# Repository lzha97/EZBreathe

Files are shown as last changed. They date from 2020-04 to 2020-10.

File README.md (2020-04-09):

# DIY-Ventilator-Design-Challenge
Project Proposal for Columbia University DIY-Ventilator-Design-Challenge (April 2-6)

https://engineering.columbia.edu/diy-ventilator-challenge

**Project Team Members:** Annie Lin, Mojde Yadollahikhales, Isabela Yepes, Lillian Zha 

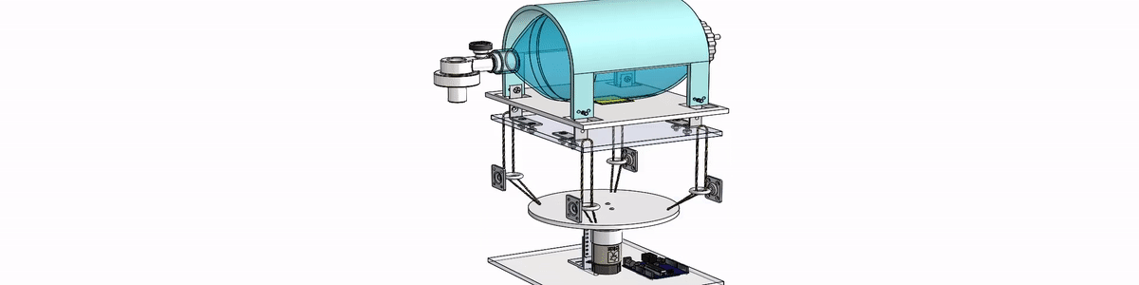
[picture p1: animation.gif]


## Included: 

- Animation of Pump Mechanism 
- CAD files for design parts (credit to Annie Lin)
- Total Assembly CAD file
- Proposal Presentation
- mp4 of Animation

## To be added: 

- Arduino Code (if our project gets selected for funding)

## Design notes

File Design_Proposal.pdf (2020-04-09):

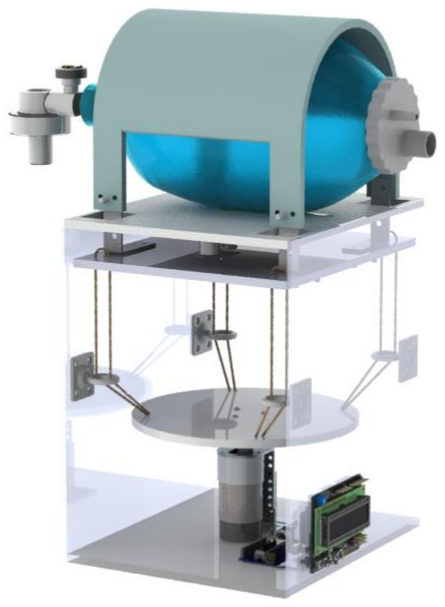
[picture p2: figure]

# EZBreathe

### Automated Ambu-Bag Pump

Annie Lin
SEAS 20’
zl2542@columbia.edu
(469)-583-7481

Isabela Yepes
SEAS 22’
imy2103@columbia.edu
(914) 308-0641

Mojde Yadollahikhales
SEAS 20’
my2511@columbia.edu
(832) 664-0195

Lillian Zha
SEAS 20’
lz2527@columbia.edu
(972)-352-9532

## COVID-19 DIY Ventilator Design Challenge Proposal

GitHub Link (https://github.com/lzha97/DIY-Ventilator-Design-Challenge)

# Overview

### - Pumping Animation - Motivation Highlights - Our Team!

# Link to Animation Video

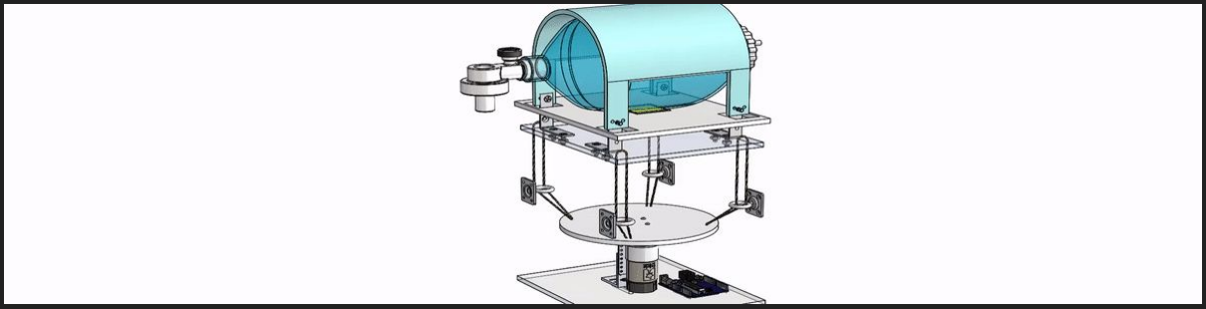
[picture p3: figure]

https://youtu.be/aiGK7Tza4vM

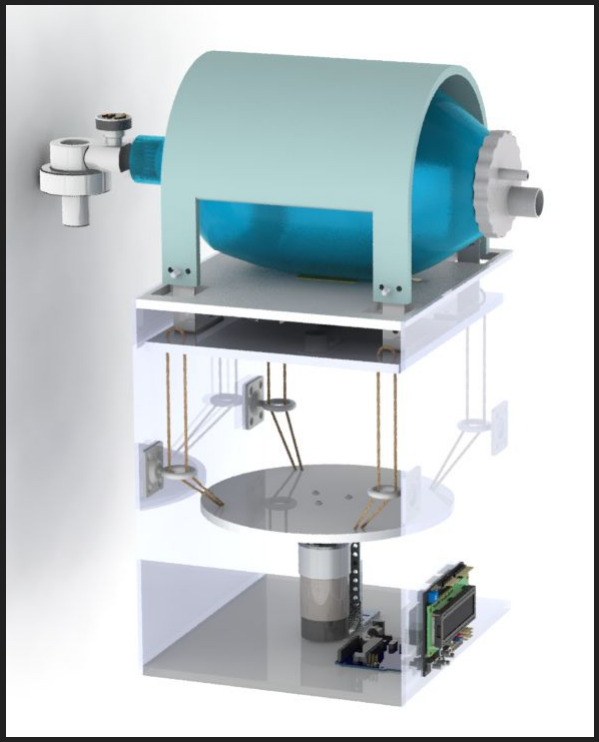
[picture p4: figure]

# Motivation Highlights

- Easy ambu-bag replacement - Cover grips to fit any ambu-bag volume size as it squeezes - Force applied from only one motor (few mechanical parts) - No 3D printing required - True DIY - quick and easy assembly with readily available pieces - Low resource countries with no makerspace facilities can replicate - Operates for at least 15 days - Attempt at patient-paced inhalation

# Our Team!

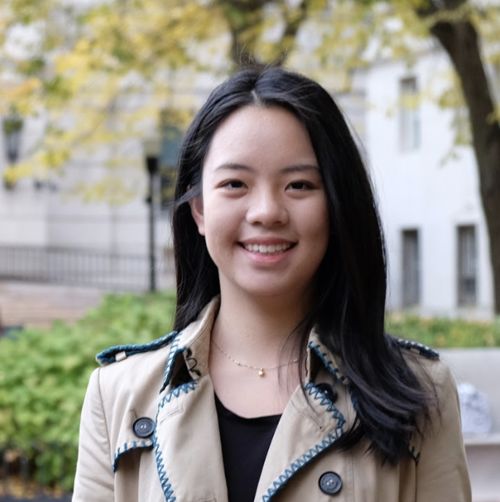
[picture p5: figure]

Annie Lin
Mechanical Engineering

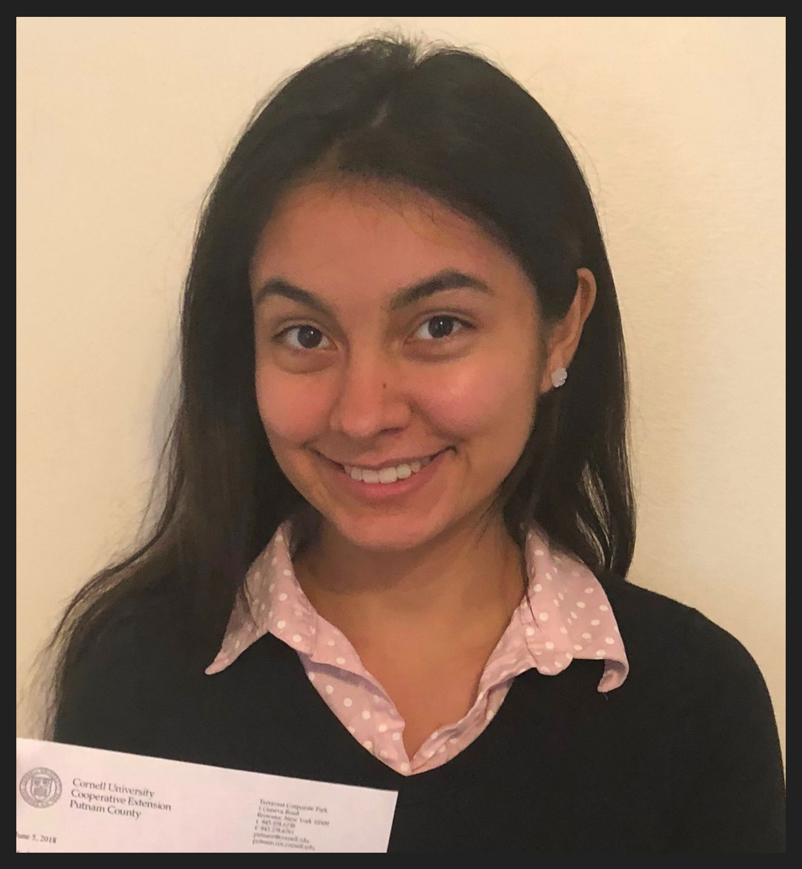
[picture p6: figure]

Isabela Yepes
Earth & Environmental
Engineering

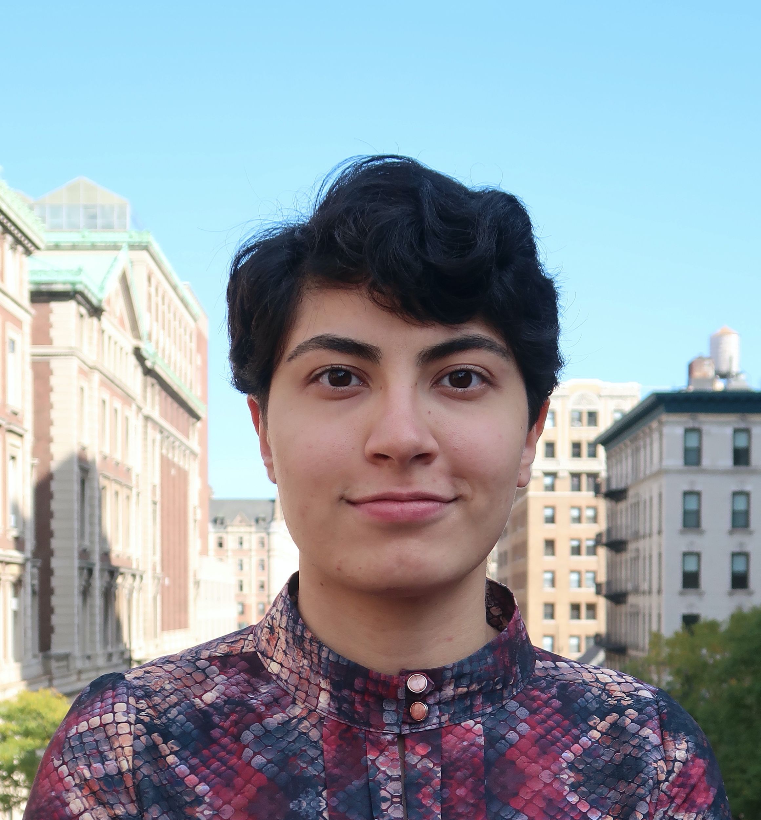
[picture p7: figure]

Mojde Yadollahikhales
BioMedical Engineering

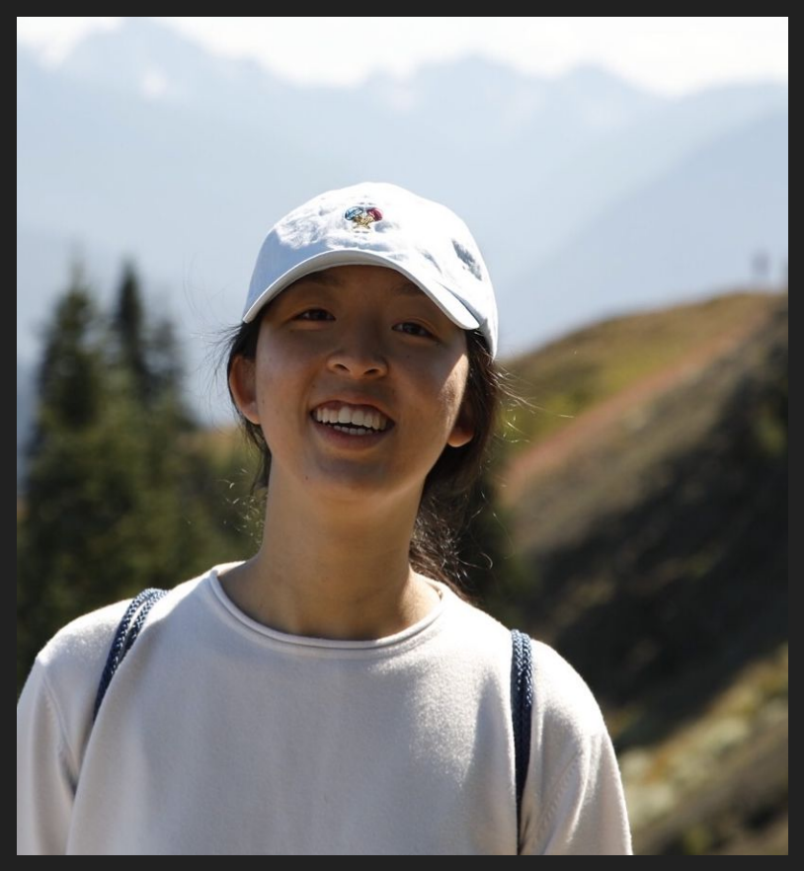
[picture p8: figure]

Lillian Zha
Computer Science

# Design Schema

### - Design Overview - CAD Renderings - String Attachment - Exploded Parts View - Design Versions for Ultrasonic Sensor Placement - Electronic Schematics

# Design Overview

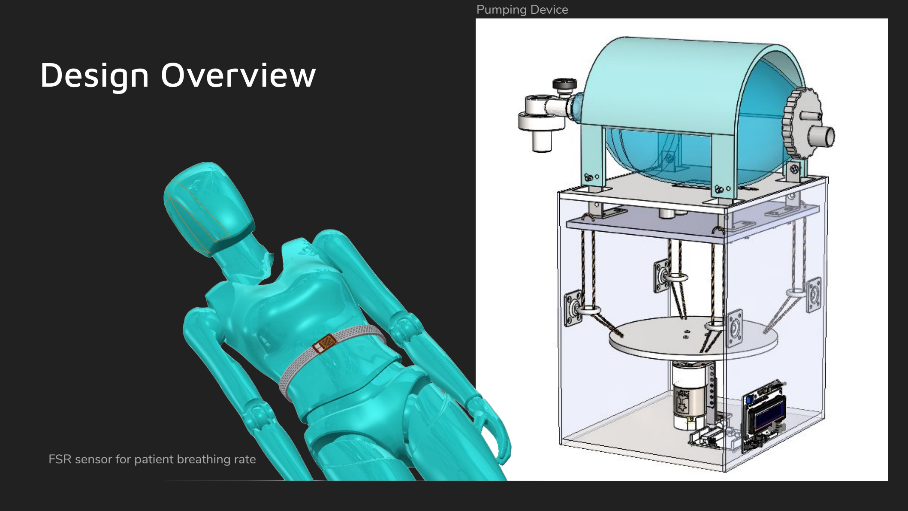
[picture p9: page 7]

FSR sensor for patient breathing rate

Pumping Device

# CAD Rendering

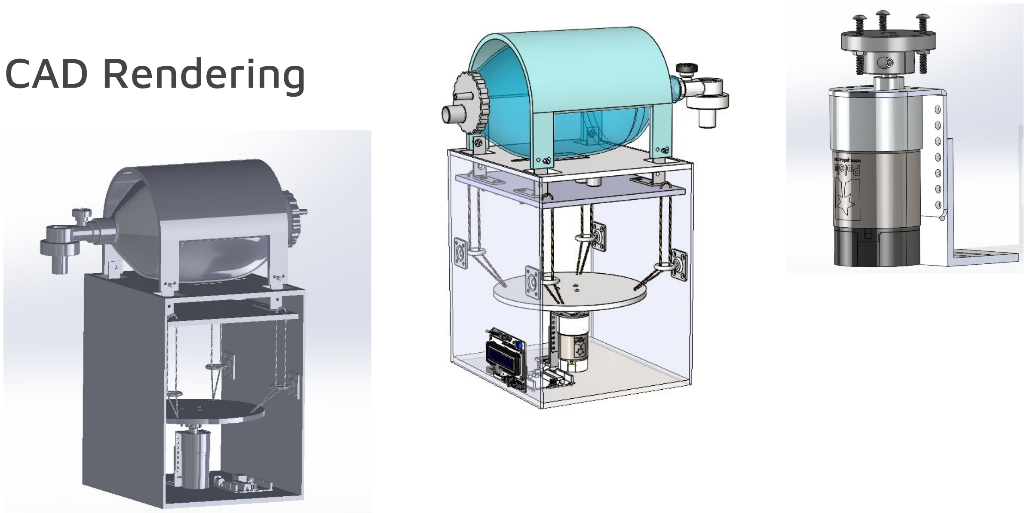
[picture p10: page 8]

# CAD Rendering (Continued)

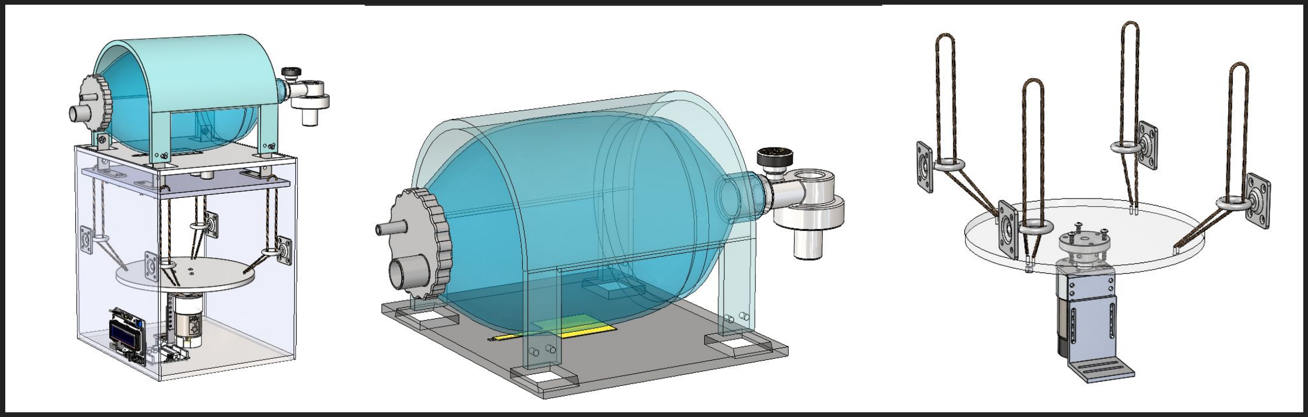
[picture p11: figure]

# String Attachment

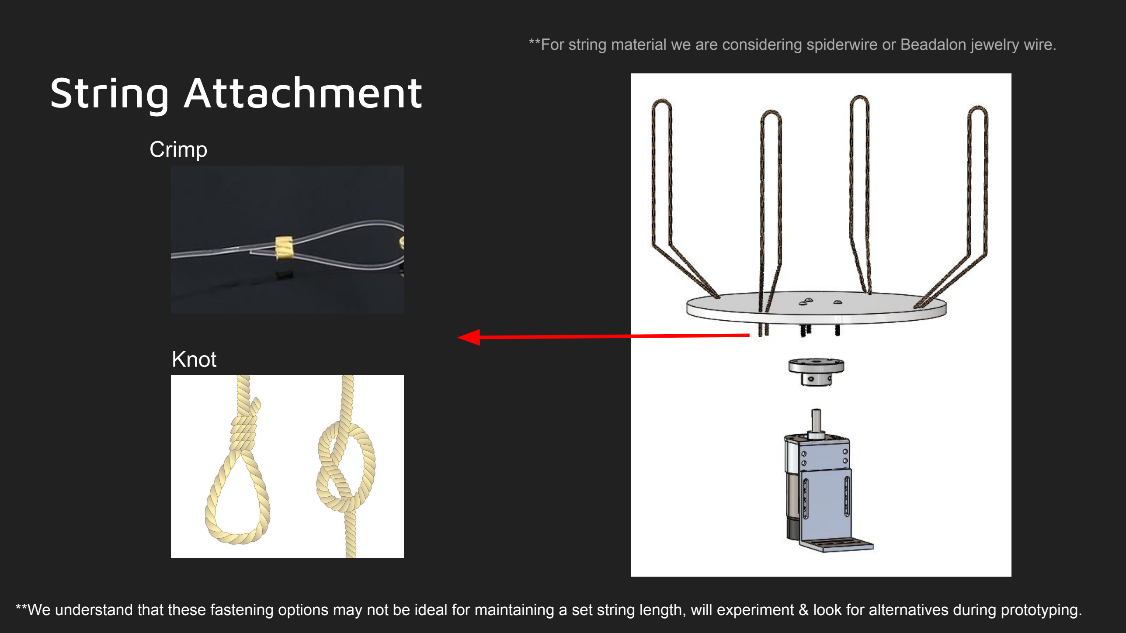
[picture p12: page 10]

**We understand that these fastening options may not be ideal for maintaining a set string length, will experiment & look for alternatives during prototyping.

Knot

Crimp

**For string material we are considering spiderwire or Beadalon jewelry wire.

# Exploded Parts View

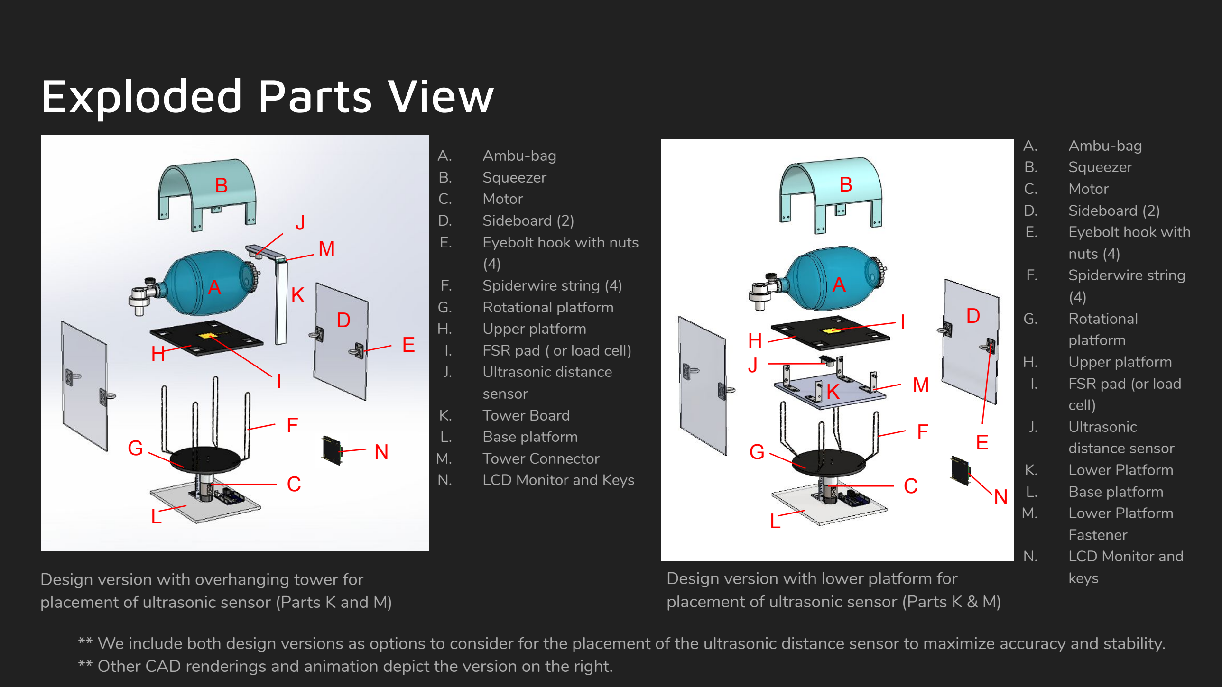
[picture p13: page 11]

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
A. Ambu-bag
B. Squeezer
C. Motor
D. Sideboard (2)
E. Eyebolt hook with
nuts (4)
F. Spiderwire string
(4)
G. Rotational
platform
H. Upper platform
I. FSR pad (or load
cell)
J. Ultrasonic
distance sensor
K. Lower Platform
L. Base platform
M. Lower Platform
Fastener
N. LCD Monitor and
keys

A

B

Design version with overhanging tower for placement of ultrasonic sensor (Parts K and M)

Design version with lower platform for placement of ultrasonic sensor (Parts K & M)

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
** We include both design versions as options to consider for the placement of the ultrasonic distance sensor to maximize accuracy and stability. ** Other CAD renderings and animation depict the version on the right.

A. Ambu-bag
B. Squeezer
C. Motor
D. Sideboard (2)
E. Eyebolt hook with nuts
(4)
F. Spiderwire string (4)
G. Rotational platform
H. Upper platform
I. FSR pad ( or load cell)
J. Ultrasonic distance
sensor
K. Tower Board
L. Base platform
M. Tower Connector
N. LCD Monitor and Keys

N

N

# K,M Design Parts for Ultrasonic Sensor Placement

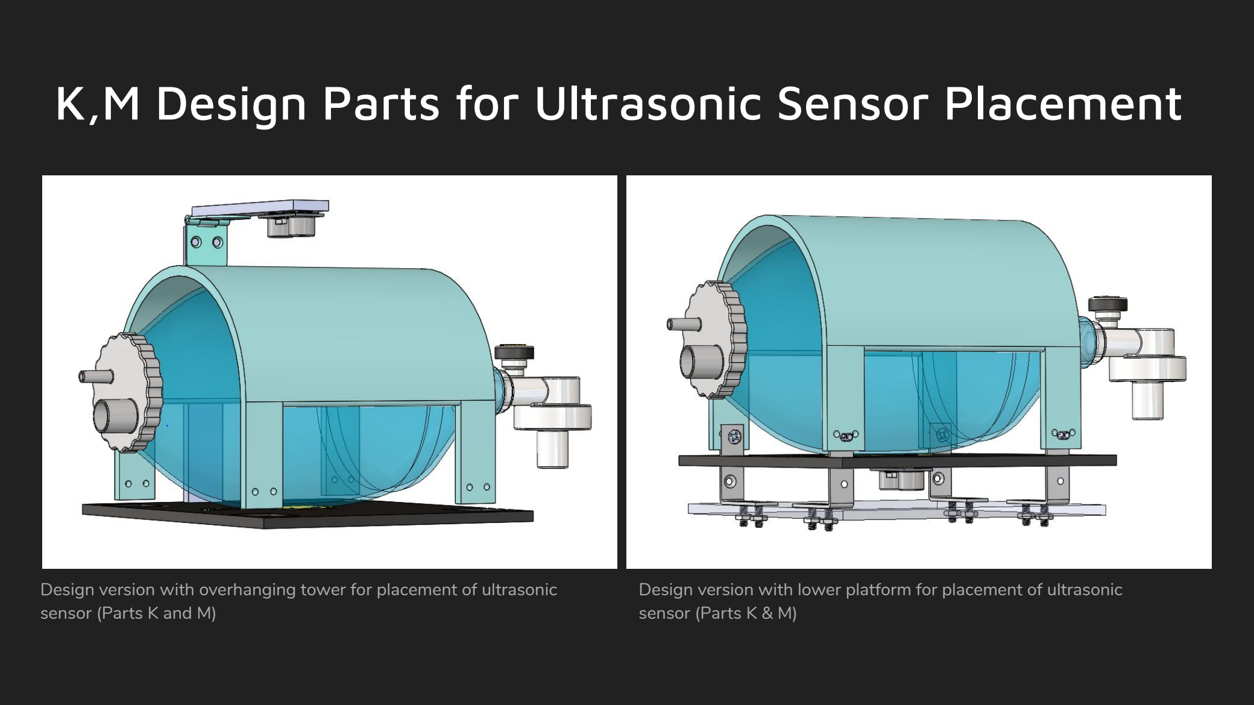
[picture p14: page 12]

Design version with overhanging tower for placement of ultrasonic sensor (Parts K and M)

Design version with lower platform for placement of ultrasonic sensor (Parts K & M)

# Electronic Schematic

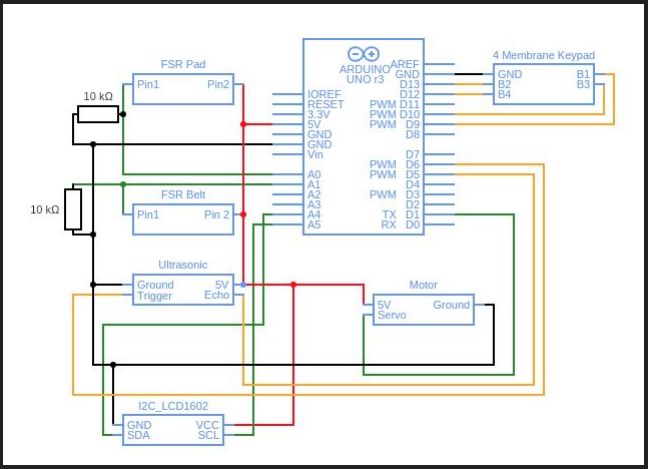
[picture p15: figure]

# Functionality Overview &

# Limitations

### - Pumping Mechanism Overview - Sensing Mechanisms Overview - Design Specifications - Sensors & Sensed Conditions - Sensing/Alarm Algorithm - Design Limitations

# Functionality Overview

### Pumping Mechanism:

This automated bag pumping design uses the concept behind linear twisted string actuators to minimize the number of mechanical parts (gears/pulleys/motors/servos etc.) needed to build the DIY pump.

The main components consist of a single motor, string and plastic squeezer above the bag.

When the motor rotates, the strings are twisted so that their overall vertical length is decreased. This decrease in vertical string length will exert a pulling force on the
squeezer placed above the bag, causing it to press down
on the bag. Increasing amplitude (pressure on ambu-bag)

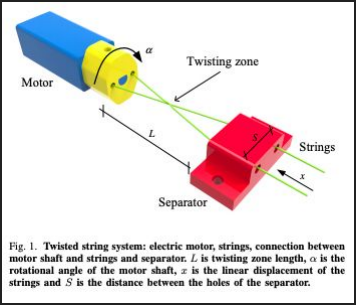
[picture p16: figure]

requires increased motor rotation. | Figure above shows theory basis for the twisting
| linear actuator mechanism from Tavakoli 2016.

# Functionality Overview (Continued)

### Sensing Mechanisms:

A shortcoming of many DIY ventilator designs are that they force patients to breathe at a set frequency. Our design uses a sensing mechanism to try to address this problem and allow patients to breathe at their own pace as long as it is above a threshold rate.

A force resistive sensor (FSR) will be placed on the patient’s stomach above the diaphragm. Ambu-bag will be pumped after detecting patient’s attempt to breathe. To prevent over-pumping of the lungs, a protective mechanism will be put in place allowing the user to set an Upper Rate Interval (URI), above which the bag will not be pumped.

The system also intakes an intrinsic Lower Rate Interval (LRI) from the user (doctor) to maintain a minimum required pump rate in the case of patient sedation/unconsciousness or lack of ability to noticeably move the stomach area.

Desired compression amplitude provided by the user will be monitored by an ultrasonic distance sensor to remove the need for constant check-ins by nurses or personnel. Similarly, the pumping rate is monitored by another FSR (or load cell) under the Ambu-bag placed under the Ambu-bag. Both of these sensors and alarm thresholds will be relative and calibrated upon powering of the system.

Finally, the FSR under the Ambu-bag and the ultrasonic distance sensor will also be used to measure the compression force and compression distance in order to ensure no leakage or other issues associated with the ambu bag and pump. All of these sensor mechanisms will work towards patient comfort and alleviating need for nurse monitoring.

# Specifications

Minimum rate: 10 bpm (pumps per min) Maximum rate: 30 bpm Maximum force: 100N (based on motor) Amplitude range: 2-15 cm Sensed Conditions: pressure drop, patient-paced inhalation, pump rate, amplitude control Safety Measures: - Alarms when the pressure drops below threshold or desired amplitude is not reached => system is failing - Has an intrinsic pump rate that will be enforced if patient breathing goes undetected

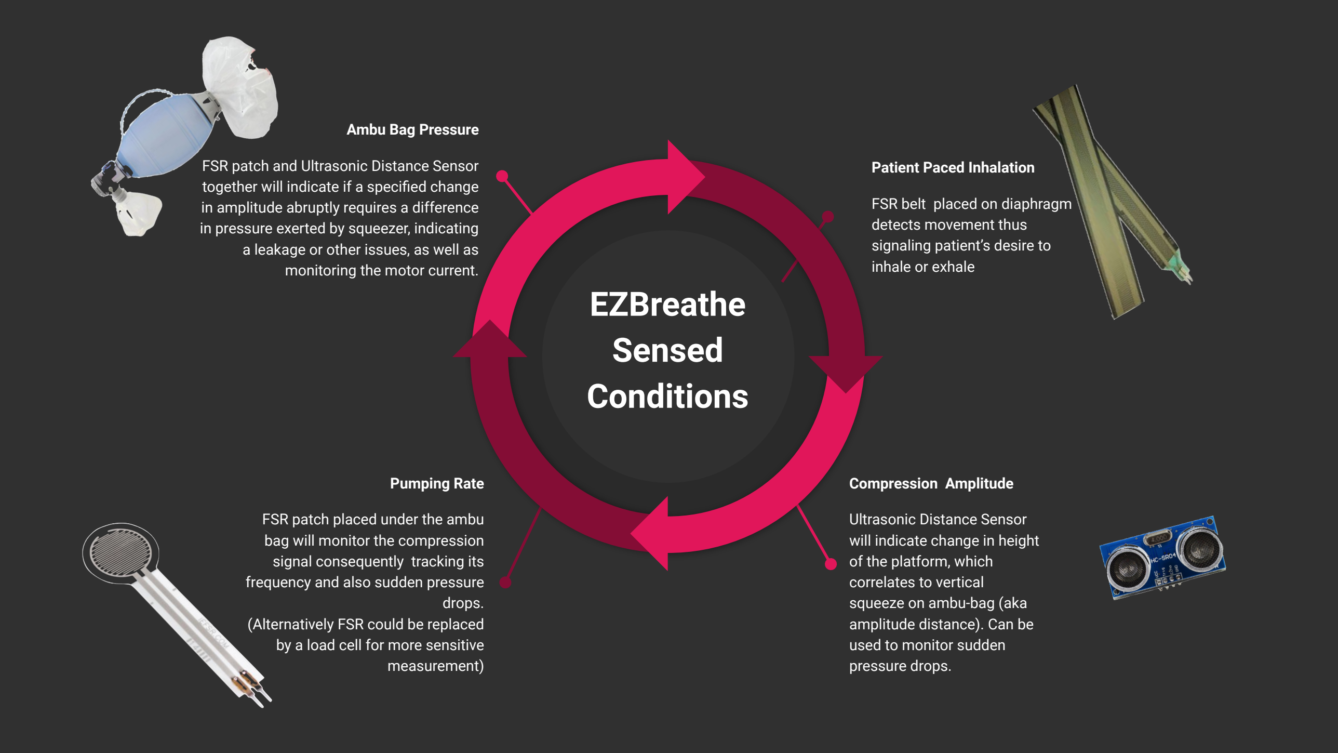
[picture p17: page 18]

Pumping Rate

FSR patch placed under the ambu bag will monitor the compression signal consequently tracking its frequency and also sudden pressure drops.
(Alternatively FSR could be replaced by a load cell for more sensitive measurement)

Ambu Bag Pressure

FSR patch and Ultrasonic Distance Sensor together will indicate if a specified change in amplitude abruptly requires a difference in pressure exerted by squeezer, indicating a leakage or other issues, as well as monitoring the motor current.

Compression Amplitude

Ultrasonic Distance Sensor will indicate change in height of the platform, which
correlates to vertical
squeeze on ambu-bag (aka
amplitude distance). Can be used to monitor sudden
pressure drops.

Patient Paced Inhalation

FSR belt placed on diaphragm detects movement thus
signaling patient’s desire to inhale or exhale

### EZBreathe Sensed Conditions

# Sensing Algorithm

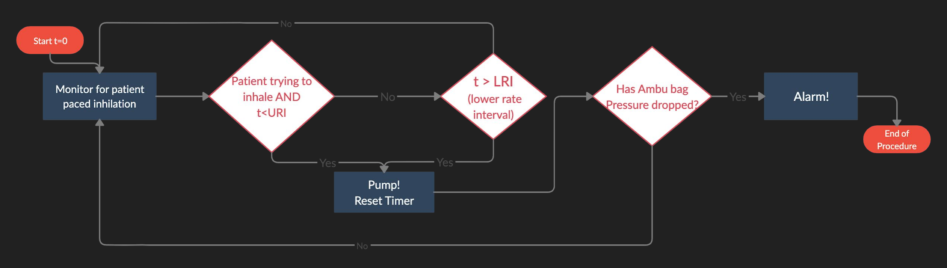
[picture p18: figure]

Pumping rate and amplitude control will also be monitored periodically by the FSR under the ambu-bag and the ultrasonic distance sensor to ensure compliance with inputted requirements after automatic calibration.

Input from user: amplitude, pumping rate, pressure range
Self-paced inhalation mode also includes: LRI and URI (defined in earlier slide)

# Limitations

### Known issues

Lack of air warming and humidifier can shock lungs in a sedated patient.

Pressure decrease sensor is indirect, not inside of the ambu bag itself, which may decrease accuracy (to account for this we have many redundant sensors measuring amplitude distance, compression force and motor current)

Some friction is expected, however we try to mitigate that using spiderwire fishing fiber which easily knots and has high strain tolerance.

Crimps or knots may not be ideal for maintaining standard string length. We will experiment and look for alternatives during prototyping.

We considered a color sensor on the manometer to measure pressure drops, however could not standardize it to ambu-bags.

### Omitted Features (Design Tradeoffs)

Design excluded 3D printed parts or the need for gears, in order to cut down on time of assembly and necessary resources, like 3D printers

If user has no access to laser cutter, wooden boards attached with screws is sufficient

EMG signals could have made for more accurate patient-paced inhalation, but is more expensive and requires additional circuitry.

FSR belt might not be as accurate as a mass flow meter but patient movement is assumed to be minimal.

# Build Details

** Parts and tools are given for non-3D printed build for true DIY, however parts can be 3D printed for efficiency and more ideal design.

### - Tools List & Durability Estimate - Parts List - Requested Build Funding

# Tools for Construction

## - Laser cutter (Optional) - Screws & Screwdrivers $10 or acrylic glue (if available) - Wire cutter $5 - Solder gun & solder $28

## Estimated number of hours for construction: 1-2 hrs

## Estimated Durability* - 15 days (optimal operation: 30 days)

*Assumed values extracted from sensor datasheets and string actuators studies. (https://www.researchgate.net/publication/320076454_A_Study_on_Life_Cycle_of_Twisted_String_Actuators_Preliminary_Results/link/59d18c4e4585150177f3d4e0/download)

# Full Parts List

Materials: | Electronics: Name | Number | Total Cost ($)
1 | Servo Motor (https://www.amazon.com/ANNIMOS-Digital-Waterproof-DS3218MG-Control/dp/B076CNKQX4) | 1 | 19
2 | FSR 402 (https://www.adafruit.com/product/166) (or Load Cell) (https://www.amazon.com/Degraw-amplifier-weight-Arduino-Bathroom/dp/B075Y5R7T7/) | 1 | ~13
3 | LCD Monitor (https://www.amazon.com/dp/B019K5X53O) | 1 | 9
4 | Touch Buttons 4 (https://www.amazon.com/Adafruit-Membrane-Keypad-Extras-ADA1332/dp/B00OKCRZ70) | 1 | 6
5 | FSR Belt (https://www.amazon.com/Adafruit-Extra-long-force-sensitive-resistor-FSR/dp/B01BMREV4A?s=electronics) | 1 | 20
6 | Sonar Distance Sensor (https://www.adafruit.com/product/3942) | 1 | 4
7 | Resistors (https://www.mouser.com/ProductDetail/KOA-Speer/MOS1CT528A103J) | 1 | 1
8 | Arduino Uno (https://www.robotshop.com/en/arduino-uno-r3-usb-microcontroller.html) | 1 | 22
9 | Breadboard (https://www.mouser.com/ProductDetail/BusBoard-Prototype-Systems/BB400?qs=VEfmQw3KOatyolZg67TKvw%3D%3D) | 2 | 11
Total | 10 | 105
| Name | Number | Total Cost ($)
1 | Ambu bag (https://www.amazon.com/Jarchii-Breathing-Professional-Use%F0%9D%90%8C%F0%9D%90%9A%F0%9D%90%A7%F0%9D%90%AE%F0%9D%90%9A%F0%9D%90%A5-%F0%9D%90%91%F0%9D%90%9E%F0%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) | 1 | ~30
2 | Spiderwire (https://www.amazon.com/Spiderwire-SDR4B80G-125-Dura-4-Braided-Fishing/dp/B07HJ4TRW5) or Stringing Wire (https://www.amazon.com/Beadalon-JW03T-1-Stainless-Stringing-0-018-Inch/dp/B00D3KOYTW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) | 1 | ~15
3 | Plywood (https://www.homedepot.com/p/Columbia-Forest-Products-3-4-in-x-2-ft-x-2-ft-PureBond-Red-Oak-Plywood-Project-Panel-Free-Custom-Cut-Available-2854/204771251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) | 2 (2x2) | ~20
4 | Screws (https://www.mcmaster.com/screws/tapping-wood-and-drywall-screws/screws-for-drywall-5/) | 12 | 2
5 | Nuts (https://www.mcmaster.com/hex-nuts/medium-strength-steel-hex-nuts-grade-5/) | 12 | 4
6 | EyeBolt Screws (https://www.mcmaster.com/hooks//eyebolts/eyebolts-with-nuts-for-lifting/) | 4 | 16
7 | Wires (https://www.sparkfun.com/products/11026) | 1 | 2
8 | Acrylic (https://www.amazon.com/US-Art-Polystyrene-Thermforming-Protection/dp/B078QCJ3X1?ref_=fsclp_pl_dp_3) (or bendable plastic) (https://www.amazon.com/Mybecca-54-Inch-Multipurpose-Upholstery-Projects/dp/B015QDB9KK) or Black Mesh Tarp (https://www.tarpsplus.com/black-mesh-tarps-6x10.html)
| 1 | 10 - 32
Total | 34 | 110

An advantage of this design is that it requires minimal mechanical parts for non-sensor functionality. The DIY design can be built without a 3D printer or laser cutter (however having those is preferred) using hardboard, power drill/screwdriver and screws/bolts.

# Requested Funding

### Number of parts: 44

### Total cost of parts: ~$215

### Total cost of tools: ~$50

### Services: $0

### Unanticipated Expenses (for spare parts & experimentation): $300

### Total requested funding: $565

Note: Access to a laser cutter is ideal for creating the platform (wooden boards/hardboards suffice as substitutes)

# References & Acknowledgements

Sources referenced for technicalities or inspiration

Patient dependent breathing rate
- Ventilator Design Guide (https://www.youtube.com/watch?v=7vLPefHYWpY&feature=youtu.be)

Twisted String Actuation
- Impedance Controlled Twisted String Actuator (https://www.youtube.com/watch?v=H6MRQbixJ-0)
- Twisted String Actuators: Surprisingly Simple, Cheap, and High Gear Ratio (http://www.hizook.com/blog/2015/01/13/twisted-string-actuators-surprisingly-simple-cheap-and-high-gear-ratio)
- A study on Life cycle of Twisted String Actuators (https://www.youtube.com/watch?v=PABVsuV7Y1M)
- A_Study_on_Life_Cycle_of_Twisted_String_Actuators_Preliminary_Results (https://www.researchgate.net/publication/320076454_A_Study_on_Life_Cycle_of_Twisted_String_Actuators_Preliminary_Results/link/59d18c4e4585150177f3d4e0/download)
- A_study_on_twisted_string_actuation_systems_Mathematical_model_and_its_experimental_evaluation (https://www.researchgate.net/publication/261353777_A_study_on_twisted_string_actuation_systems_Mathematical_model_and_its_experimental_evaluation/link/594c6b5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)
- Twisted String Actuators : Life Cycle , Twisting inside Bowden Cables , and Passive Return Mechanisms (https://pdfs.semanticscholar.org/9723/e2fc8ef0ded3ccaf82d948210c254c0271ff.pdf)
- A Compact Two-Phase Twisted String Actuation System: Modeling and Validation (https://arxiv.org/pdf/1610.01117.pdf)

CAD Models
- https://drive.google.com/file/d/1qLUrDD97_HMPjhYwgrHzDOVVLkduIGcC/view?usp=sharing
- https://grabcad.com/library/lisa-dummy-1
- https://grabcad.com/library/lcd-keypad-shield-1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 (https://grabcad.com/library/lcd-keypad-shield-1)

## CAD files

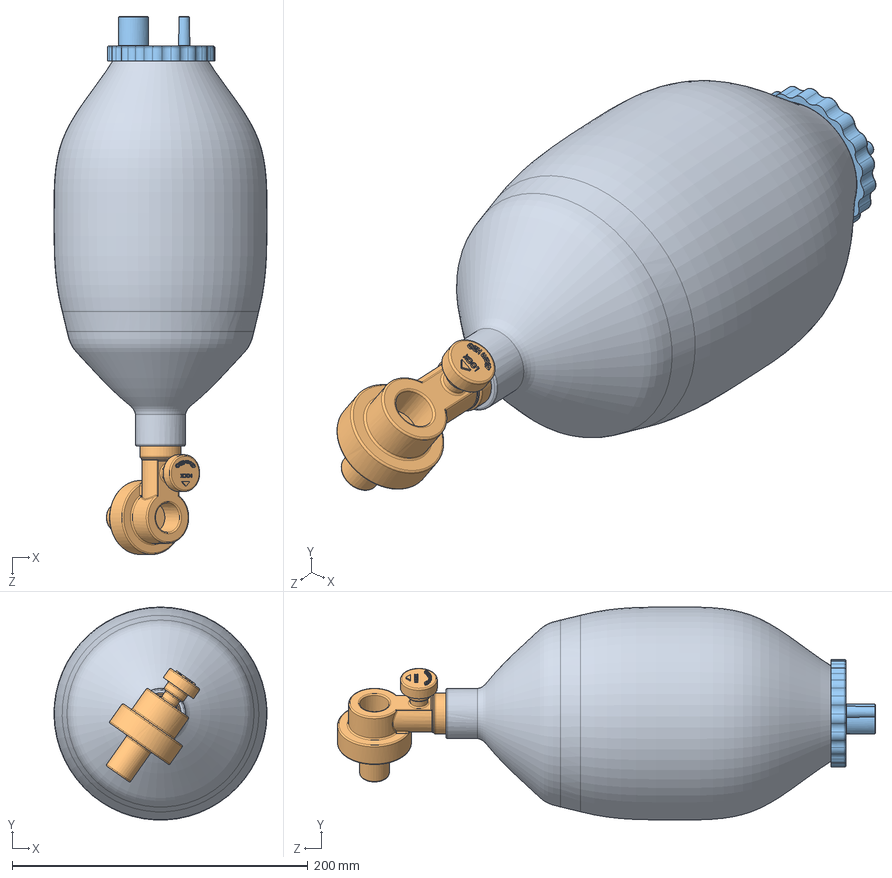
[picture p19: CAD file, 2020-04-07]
Assem13-CADfiles/Ambubag2.SLDASM
144.0 x 143.9 x 363.7 mm
AMBU BAG1
ambubag part
butelie 2

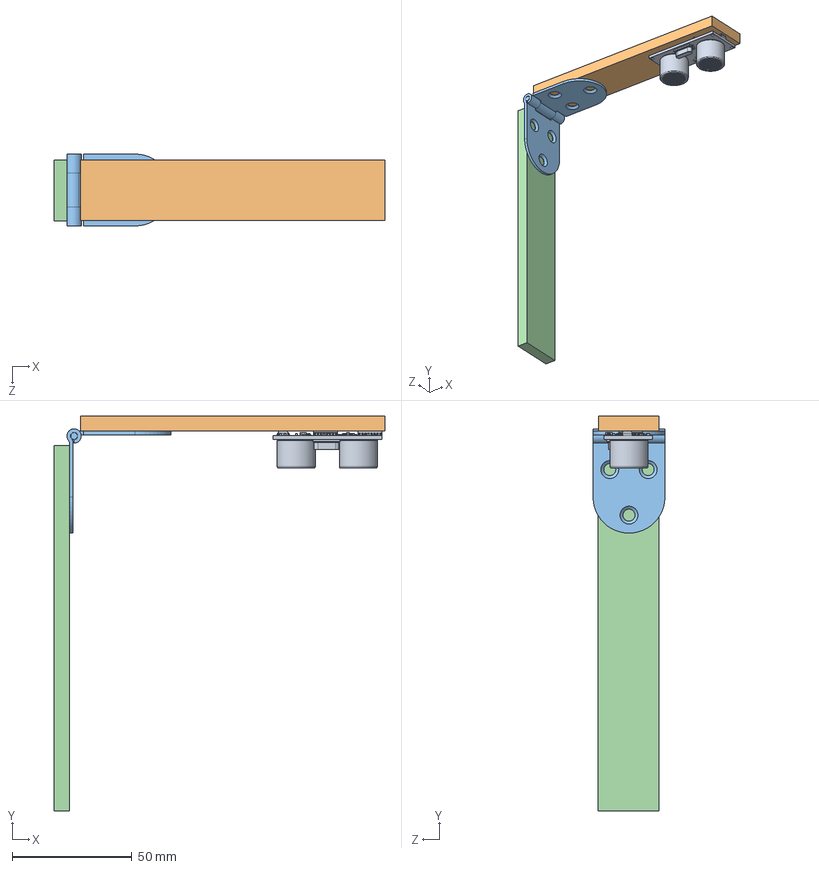
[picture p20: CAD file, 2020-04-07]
Assem13-CADfiles/tower.SLDASM
138.0 x 164.8 x 30.0 mm
HC-SR04
tower - h
Hinge fin x 2
tower - v

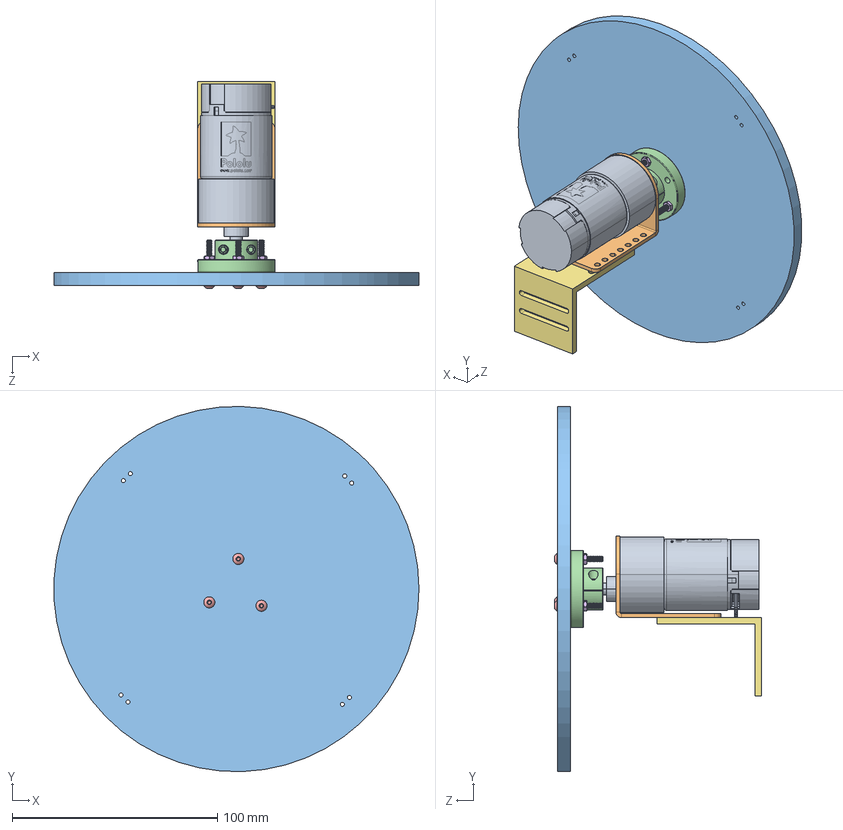
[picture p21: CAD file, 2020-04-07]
Assem13-CADfiles/Motor + disk.SLDASM
177.7 x 177.7 x 100.8 mm
37d-gearmotor-19-30-encoder
pololu-stamped-aluminum-L-bracket-for-37d-mm-metal-gearmotors
string disk
9684T270_FLANGE-MOUNT SHAFT COLLAR
92949A114_18-8 SS BUTTON HEAD HEX DRIVE SCREW x 3
90730A005_TYPE 18-8 STAINLESS STEEL NARROW HEX NUT x 3
motor bracket

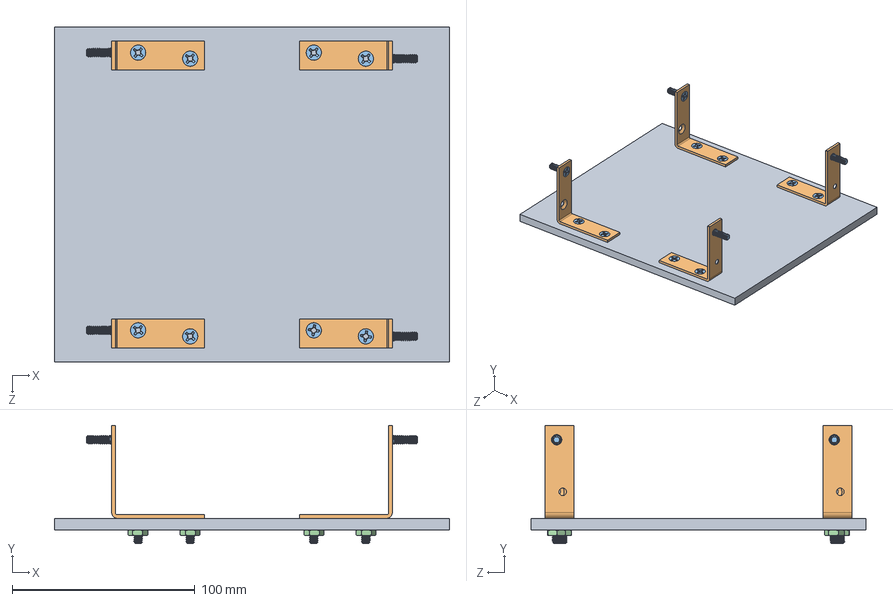
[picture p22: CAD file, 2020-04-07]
Assem13-CADfiles/middle shelf.SLDASM
215.9 x 64.6 x 182.9 mm
shelf
1556A540_BRACKET x 4
91771A244_18-8 SS FLAT HEAD PHILLIPS MACHINE SCREW x 12
90480A011_LOW-STRENGTH STEEL HEX NUT x 8

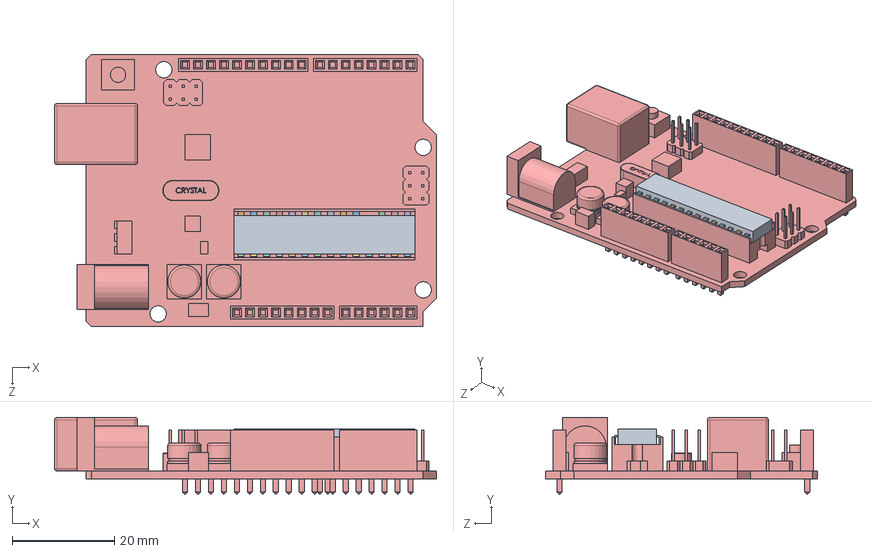
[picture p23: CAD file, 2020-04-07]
Assem13-CADfiles/ArduinoUNOR3.SLDASM
74.8 x 15.1 x 53.3 mm
ArduinoUNOR3_27
ArduinoUNOR3_24
ArduinoUNOR3_29
ArduinoUNOR3_19
ArduinoUNOR3_12
ArduinoUNOR3_25
ArduinoUNOR3_26
ArduinoUNOR3_13
ArduinoUNOR3_17
ArduinoUNOR3_21
ArduinoUNOR3_3
ArduinoUNOR3_30
ArduinoUNOR3_23
ArduinoUNOR3_11
ArduinoUNOR3_22
ArduinoUNOR3_15
ArduinoUNOR3_20
ArduinoUNOR3_9
ArduinoUNOR3_18
ArduinoUNOR3_14
ArduinoUNOR3_2
ArduinoUNOR3_6
ArduinoUNOR3_5
ArduinoUNOR3_4
ArduinoUNOR3_7
ArduinoUNOR3_10
ArduinoUNOR3_8
ArduinoUNOR3_28
ArduinoUNOR3_16

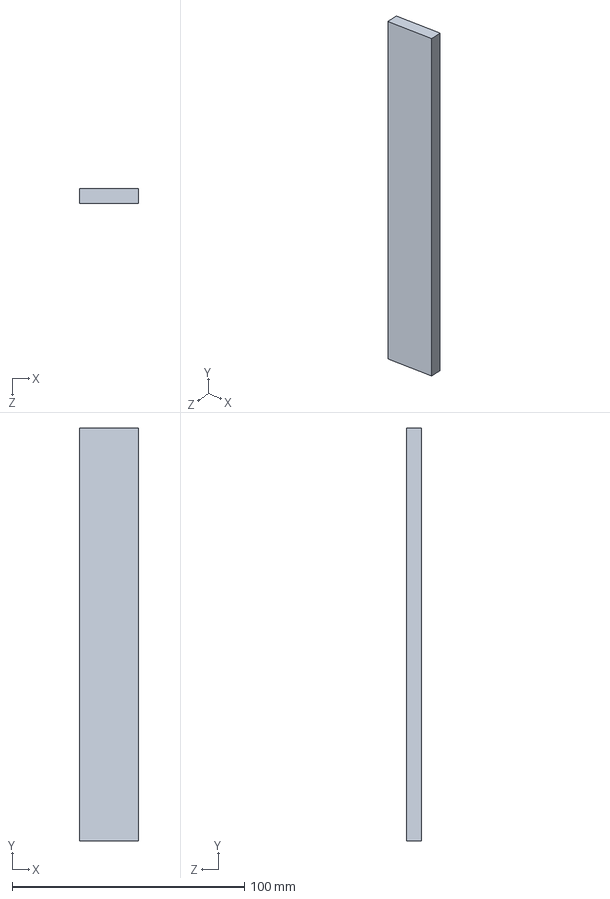
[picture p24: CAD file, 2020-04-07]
Assem13-CADfiles/tower - v.SLDPRT
25.4 x 177.8 x 6.35 mm

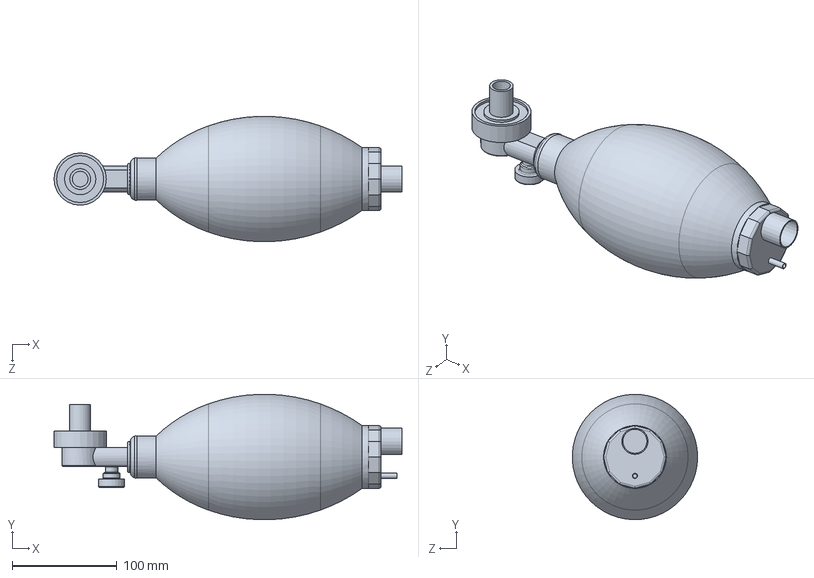
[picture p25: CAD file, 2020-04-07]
Assem13-CADfiles/Ambu Bsg.SLDPRT
332.5 x 119.7 x 119.7 mm

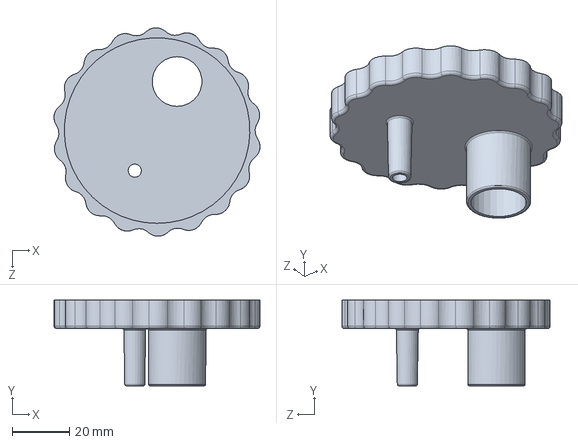
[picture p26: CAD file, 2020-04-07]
Assem13-CADfiles/butelie 2.SLDPRT
72.2 x 30.0 x 73.0 mm

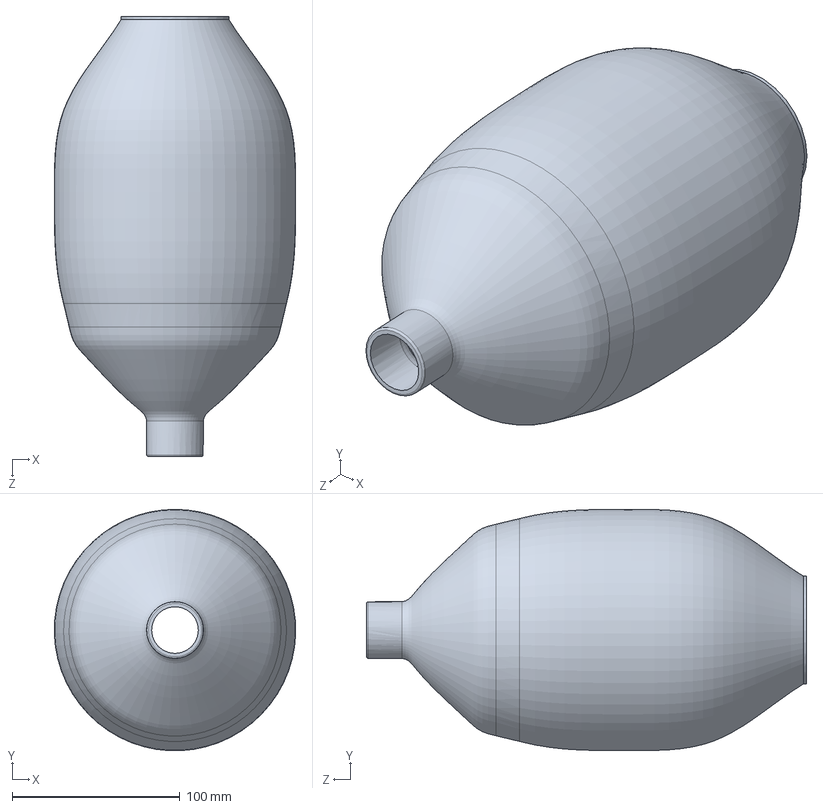
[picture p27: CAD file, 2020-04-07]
Assem13-CADfiles/AMBU BAG1.SLDPRT
144.0 x 143.9 x 262.5 mm

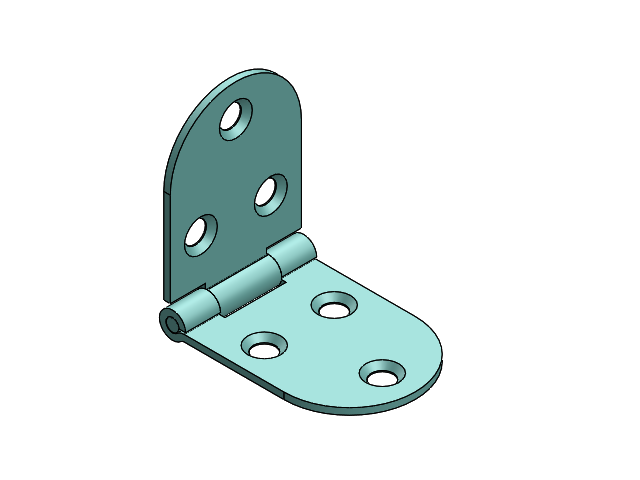
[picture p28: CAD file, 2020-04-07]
Assem13-CADfiles/Hinge.SLDASM
Hinge fin x 2

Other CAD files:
Assem13-CADfiles/ArduinoUNOR3_24.sldprt
Assem13-CADfiles/ArduinoUNOR3_20.sldprt
Assem13-CADfiles/ArduinoUNOR3_8.sldprt
Assem13-CADfiles/ArduinoUNOR3_26.sldprt
Assem13-CADfiles/ArduinoUNOR3_9.sldprt
Assem13-CADfiles/ArduinoUNOR3_29.sldprt
Assem13-CADfiles/ArduinoUNOR3_3.sldprt
Assem13-CADfiles/ArduinoUNOR3_27.sldprt
Assem13-CADfiles/1556A540_BRACKET.SLDPRT
Assem13-CADfiles/3080T110_UNTHRD STL ROUTING EYEBOLT.SLDPRT
Assem13-CADfiles/31665T100_SS SWIVEL TIE-DOWN RING.SLDPRT
Assem13-CADfiles/37d-gearmotor-19-30-encoder.SLDPRT
Assem13-CADfiles/6412K110_BLK-OXIDE STL SET SCREW RIGID SHAFT COUPLING.SLDPRT
Assem13-CADfiles/90480A011_LOW-STRENGTH STEEL HEX NUT.SLDPRT
Assem13-CADfiles/90730A005_TYPE 18-8 STAINLESS STEEL NARROW HEX NUT.SLDPRT
Assem13-CADfiles/91771A244_18-8 SS FLAT HEAD PHILLIPS MACHINE SCREW.SLDPRT
Assem13-CADfiles/92949A114_18-8 SS BUTTON HEAD HEX DRIVE SCREW.SLDPRT
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

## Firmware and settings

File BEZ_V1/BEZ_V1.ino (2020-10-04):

// Include libraries:
#include <NewPing.h>
#include <Wire.h>
#include <LiquidCrystal_I2C.h>

// Define pins and max distance for Ultra Sound(HC_US):
#define trigPin  2 //create a Parallax Ping to use only one I/O ping
#define echoPin  2 //use one digital pin for both
#define MAX_DISTANCE 100 // Maximum distance we want to ping for (in centimeters). Maximum sensor distance is rated at 400-500cm.

// pins for Ambubag FSR:
#define fsrpinA A1
#define ledpin 3

// pins for Body FSR:
#define fsrpinB A0
#define ledpin 2

//// LCD pins:
#define SDAPin A4 // Data pin
#define SCLPin A5 // Clock pin

// Sensor variables:
int fsrreading; // The current reading from the FSR
int state = HIGH; // The current state of the output pin
int previous = 0; // The previous reading from the FSR
long time = 0;  // The last time the output pin was toggled
long debounce = 40; // The debounce time, increase if the output flickers
float duration, distance; //Sonar variables

NewPing sonar(trigPin, echoPin, MAX_DISTANCE); // NewPing setup of pins and maximum distance.
LiquidCrystal_I2C lcd = LiquidCrystal_I2C(0x27,20,4); // Connect to LCD via I2C:

// Breathing intervals
int URI = 30; // breathes per minute
int LRI = 10; //bpm
int CRI; // current rate interval bpm


void setup() {
  
  Serial.begin(9600);
  pinMode(trigPin, OUTPUT); 
  pinMode(echoPin, INPUT); 

  // Initiate the LCD:
  lcd.init();
  lcd.backlight();
  
  // Set ledpin as output response for now (can add speaker later):
  pinMode(ledpin, OUTPUT);
}

void loop() {
  
  // Monitor for patient paced inhilation
  fsrreading = analogRead(fsrpinB);
  Serial.println(fsrreading); // Print for programmer checks

  // If the input just went from below 500 to above 500 and we've waited long enough to ignore any noise on the circuit, toggle the output pin and remember the time:
  if (fsrreading > 500 && previous < 500 && millis() - time > debounce) {
    CRI = 60/(millis() - time);

    if (CRI < URI){
      state = HIGH;// Trig motor for inhalation
      //pump and reset timer
      time = millis();}
    else if (CRI > LRI){
      state = HIGH;// Trig motor for inhalation
      time = millis();}
    else
      state = LOW;
  }
  digitalWrite(ledpin, state); // to be replaced by motor code
  previous = fsrreading;


  // Ambubag pressure check
  delay(50); // (20 pings/sec)

  // Distance frequency array
  int iterations = 5; //take median distance reading for higher accuracy
  duration = sonar.ping_median(iterations);
  distance = (duration / 2) * 0.0343;

  Serial.print("Distance = ");
  Serial.print(distance); // Distance will be 0 when out of set max range.
  Serial.println(" cm");

  // Pressure frequency wave on Afsr
  // Monitor for ambubag force-generated pressure
  fsrreading = analogRead(fsrpinA);
  Serial.println(fsrreading); // Print for programmer checks
  if (fsrreading > 500 && previous < 500 && millis() - time > debounce) {
    state = HIGH;}
  
  if (distance > 12 && state){
    digitalWrite(ledpin, HIGH); // Warning for pressure drop
    lcd.setCursor(0,0);
    lcd.print(" " "\xDF" "C");
    lcd.setCursor(0,1);
    lcd.print("WARNING: Ambubag Pressure Drop!");
  }

 // Print stuff on LCD Serial Monitor:
  lcd.setCursor(0,0);
  lcd.print(" " "\xDF" "C");
  lcd.setCursor(0,1);
  lcd.print("Speed: ");
  lcd.print(duration);
  lcd.print(" m/s ");
  lcd.setCursor(0,2);
  lcd.print("Distance: ");
  lcd.print(distance);
  lcd.print(" cm  ");
  delay(100);

}

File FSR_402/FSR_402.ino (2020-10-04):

/* Example code to use Force Sensitive Resistor (FSR) as toggle switch to control LED. More info: https://www.makerguides.com */

// Define pins:
#define fsrpin A0
#define ledpin 2

// Define variables:
int fsrreading; // The current reading from the FSR
int state = HIGH; // The current state of the output pin
int previous = 0; // The previous reading from the FSR
// The follow variables are long's because the time, measured in miliseconds, will quickly become a bigger number than can be stored in an int:
long time = 0;  // The last time the output pin was toggled
long debounce = 40; // The debounce time, increase if the output flickers

void setup() {
  // Begin serial communication at a baud rate of 9600:
  Serial.begin(9600);
  // Set ledpin as output:
  pinMode(ledpin, OUTPUT);
}

void loop() {
  // Read the FSR pin and store the output as fsrreading:
  fsrreading = analogRead(fsrpin);

  // Print the fsrreading in the serial monitor:
  Serial.println(fsrreading);

  // If the input just went from below 500 to above 500 and we've waited long enough to ignore any noise on the circuit, toggle the output pin and remember the time:
  if (fsrreading > 500 && previous < 500 && millis() - time > debounce) {
    if (state == HIGH)
      state = LOW;
    else
      state = HIGH;
    time = millis();
  }

  digitalWrite(ledpin, state);

  previous = fsrreading;
}

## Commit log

2020-04-07 cad files and animation
    [1556A540_BRACKET.SLDPRT, 3080T110_UNTHRD STL ROUTING EYEBOLT.SLDPRT, 31665T100_SS SWIVEL TIE-DOWN RING.SLDPRT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]
2020-04-07 added Total Assembly CAD file and Design Proposal
